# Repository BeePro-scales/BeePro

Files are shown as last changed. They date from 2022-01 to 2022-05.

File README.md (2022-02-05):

# BeePro Sms Scales
#### Hardware Design Files [Here](/Hardware)
#### Firmware file [Here](/firmware)
#### Assembly Instructions [Here](/AssemblyInstructions.md)
#### How to set the scales [Here](/Settings.md)

#### Technical Characteristics
Humidity measurement: 0 to 100% RH operating range, precision :± 4% RH (max), 0–80% RH
Temperature measurement: -25 to +60 C, ±0.4 °C (max), –10 to 85 °C
Power source: 18650 Li-Ion battery
Standby power consumption: ~1 µA (microampere)

#### SMS Of Daily Report
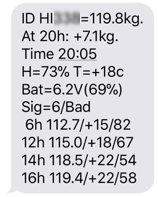
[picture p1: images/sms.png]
Sms
     
Lines
1. Scales ID and hive weight at 8pm
2. Daily beehive weight change
3. Scales time
4. Current humidity and temperature
5. Battery volts and remaining charge
6. GSM network signal quality range from 1 to 33
7. 6 hour hive weight, temperature and humidity
8. 12 hour hive weight, temperature and humidity
9. 14 hour hive weight, temperature and humidity
10. 16 hour hive weight, temperature and humidity

#### Over 1 Kg Change In 1 Hour Report
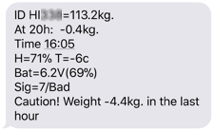
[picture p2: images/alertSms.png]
Sms Alert
   
Lines
1. Scales ID and hive weight at 8pm
2. Daily beehive weight change
3. Scales time
4. Current humidity and temperature
5. Battery volts and remaining charge
6. GSM network signal quality range from 1 to 33
7. Weight change in last hour

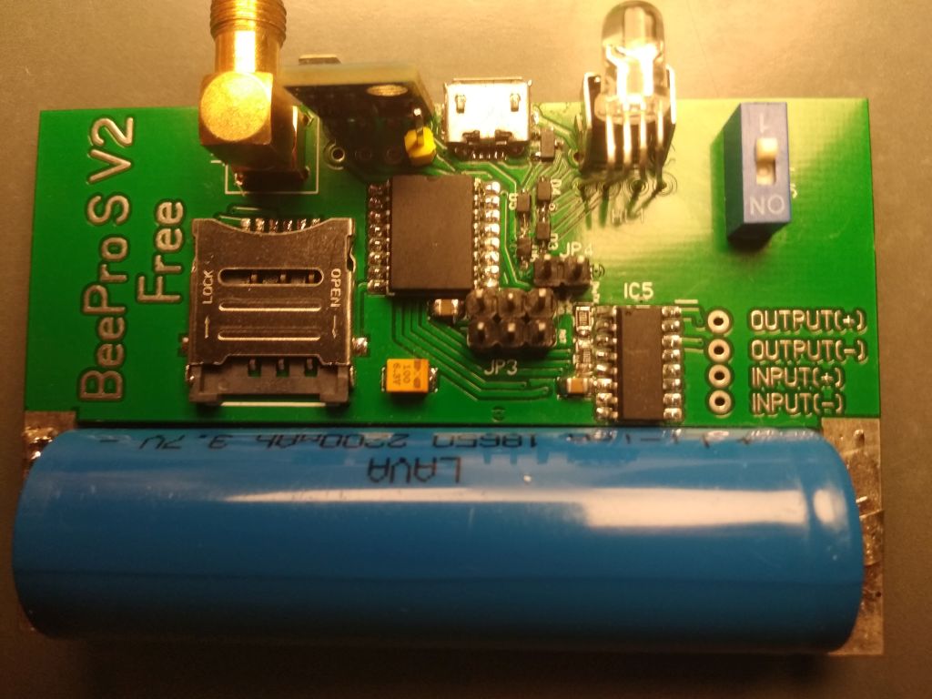
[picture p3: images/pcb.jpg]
SmsScales


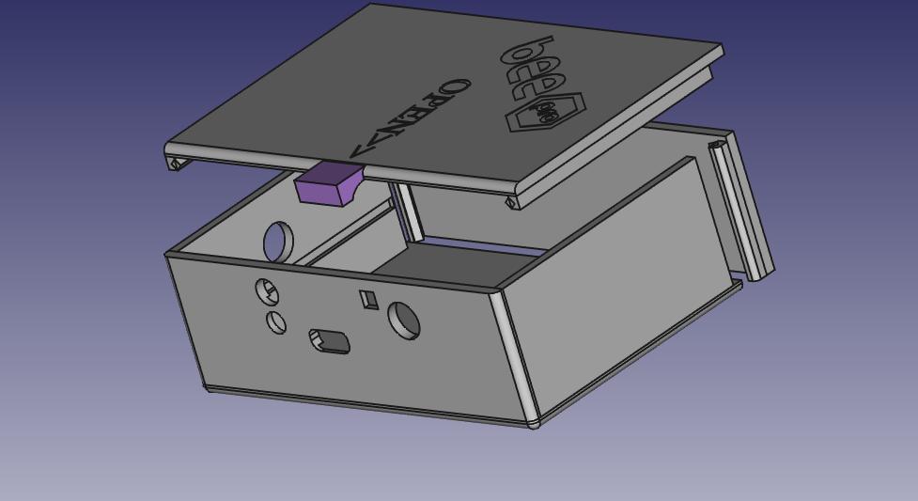
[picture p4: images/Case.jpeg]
3d Model


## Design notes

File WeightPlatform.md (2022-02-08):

# We make

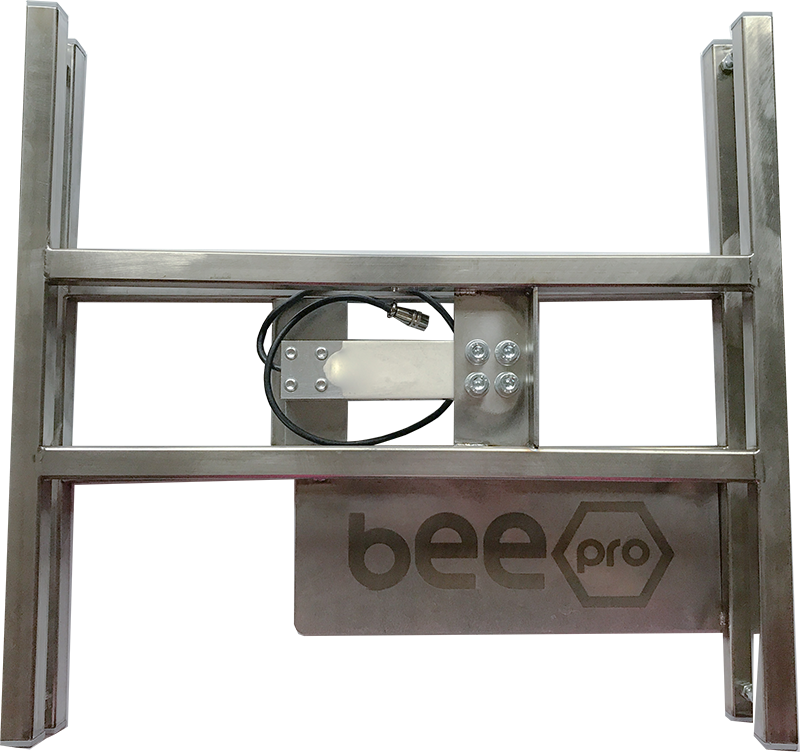
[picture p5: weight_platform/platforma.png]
Platform with sensor


# Under the hive 

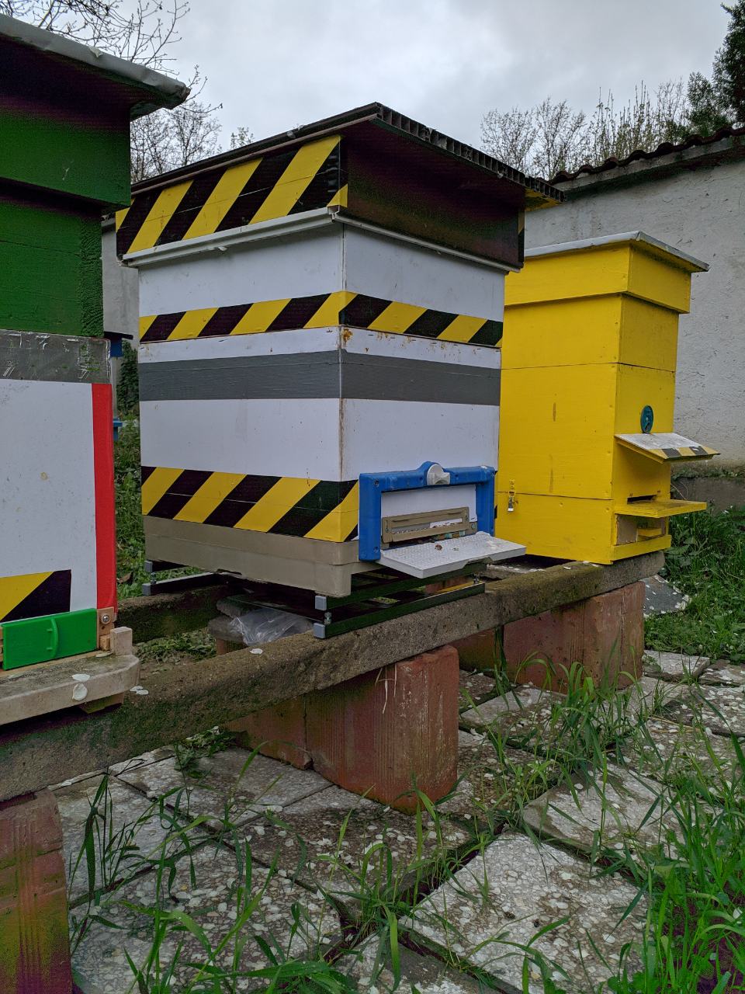
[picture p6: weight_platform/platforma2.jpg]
Platform under the hive


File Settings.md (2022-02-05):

#### Functions for scales without a screen:

Short click <3 seconds. If LED blinks for 2 times - the scales are alive and working.

Information that scales provide:

F0.1 +30000000000 LA256 4.00 01/01/2000 00:17:13
hg: 34 cls: 23 wg: 0.00

Explanation:

  - F0.1 - software version;
  - +30000000000 - phone number scales send SMS to;
  - LA256 - Unique scales ID;
  - 4.00 - battery volts;
  - 01/01/2000 00:17:13 - Scales date and time;
  - hg: 34 - Humidity;
  - cls: 23 - Temperature;
  - wg: 0.00 - Day weight difference;

#### Test and calibration mode:

-- Calibration mode:

  Hold the power button till LED turns blue, then release click:
    - Calibration mode is on for 15 seconds. You’ll need to add 1kg. weight on the scales in this period (15 seconds ).
    - In case calibration was successful - the LED blinks 2 times in green color and this means that calibration is done.

    If LED blinks 3 times in red color - calibration failed, this could be for many reasons (unconnected platform, bad sensor, etc.)

#### Send a test SMS message:

  Hold the power button till LED turns blue, hold for another 3 seconds ( do not release click when LED turns blue), when LED turns green, release click :
  
  This will send a test SMS message.

    If LED blinks 2 times in red - scales does not have master phone number (you need to set it in the scales settings )

#### Functions for scales with a screen:

Click and hold the power button for 3 seconds, when LED turns red - release click :

Screen menu :

1. Test Hardware
2. Send a Test SMS
3. Change/Add Master Number
4. Set ID
5. Set Date/Time
6. Power Off

Explanation of menu items:

1. Test Hardware - test SI7020 sensor:
  - If the test is successful, see this on the screen:

    Test RTC: OK Date: 01/01/2000 00:00:52
    Test SI7020: OK H%: 32 Celsius: 20

  - If the test failed, see this on the screen:

    Test RTC: FAIL
    or
    Test SI7020: FAIL

2. Send a Test SMS - Send a test SMS and test the GSM module.
3. Change/Add Master Number - Set the main (master) phone number to where to send the day report (scales send a report every day at 20:00 ).
4. Set ID - Set unique scales ID (this ID is visible in the SMS message )
5. Set Date/Time - Set scales date and time.
6. Power Off - Turn off scales.

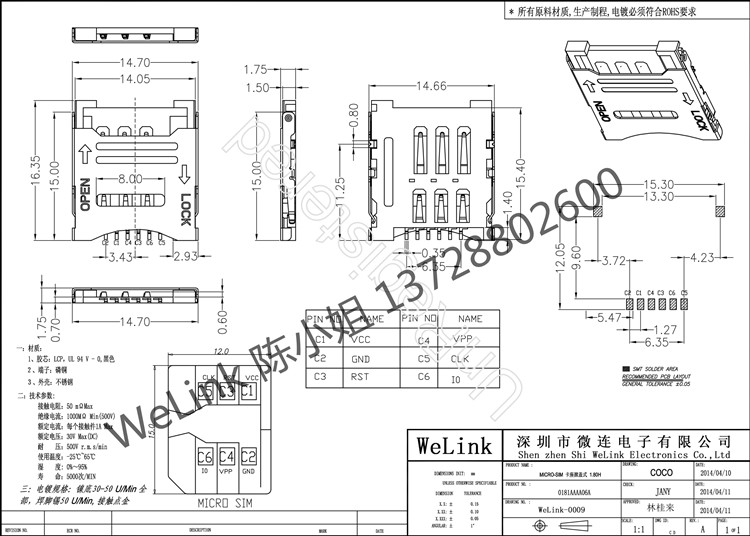
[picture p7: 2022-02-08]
Hardware/SimHolder.jpg

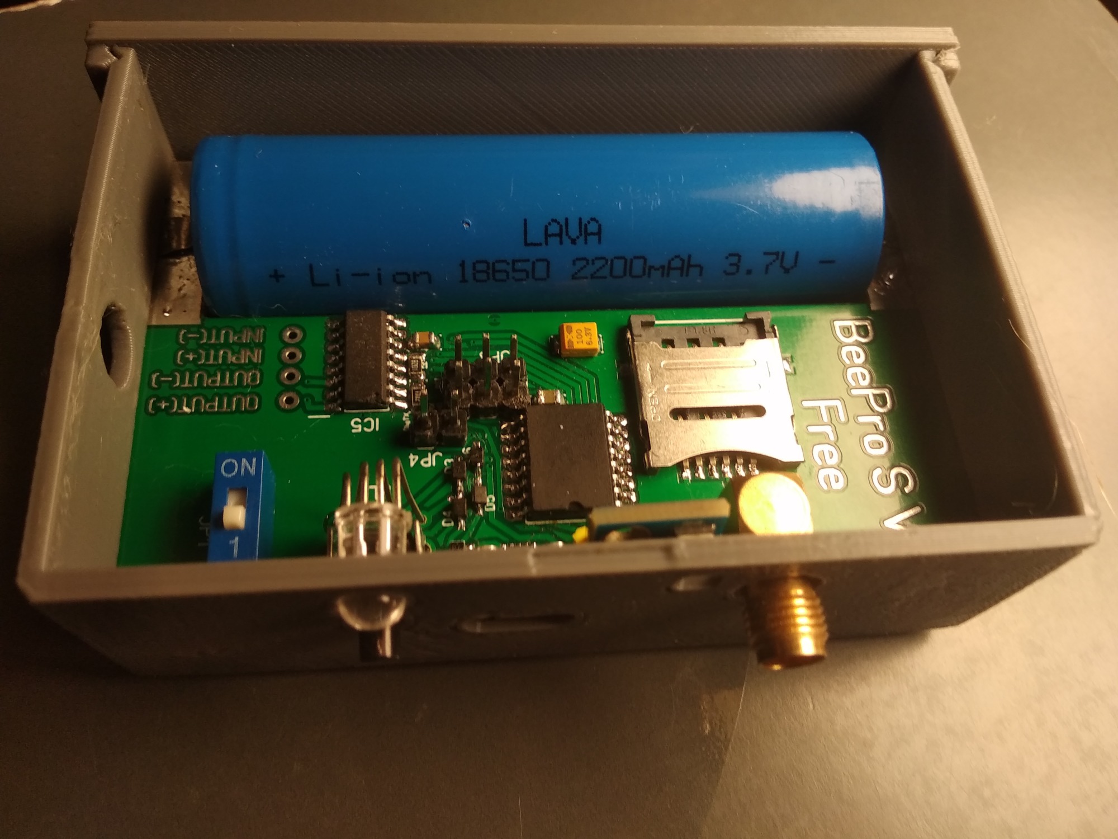
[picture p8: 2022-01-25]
images/pcbWithCase.jpg

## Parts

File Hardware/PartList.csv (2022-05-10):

No | Name | Value | Layer | Package
1 | C1 | 100uf | Top | 805
2 | C2 | 0,1uf | Top | 603
3 | C3 | 1Uf | Top | 805
4 | C4 | 1Uf | Bottom | 805
5 | C5 | 1Uf | Top | 805
6 | C6 | 0,1uf | Top | 805
7 | C6 | 1Uf | Top | 805
8 | C7 | 0,1uf | Top | 805
9 | C8 | 100uf | Bottom | 805
10 | C9 | 47Uf | Bottom | 805
11 | C10 | 47Uf | Top | 805
12 | C11 | 10uf | Top | 805
13 | IC2 | DS3231SN | Bottom | 805
14 | IC3 | Atmega328 | Top | TQFP32 Fuse : Low 0xE2 High 0xD7 Extended 0xFE
15 | IC4 | TP4057 | Top | SOT-23-6
16 | IC5 | HX711 | Bottom | SOP-16L
17 | P1 | G27Y | Bottom | ---
18 | Q1 | SI2329DS | Top | SOT-23
19 | Q2 | SI2329DS | Top | SOT-23
20 | Q3 | MMBT2222A | Top | SOT-23
21 | Q4 | MMBT2222A | Top | SOT-23
22 | Q5 | MCP1702-3.0 | Top | SOT-23A
23 | Q6 | DTA113ZCA | Top | SOT-23
24 | Q7 | DTA113ZCA | Bottom | SOT-23
Q8 MMBT2222A Bottom | SOT-23
25 | R1 | 47k | Top | 805
26 | R2 | 150R | Top | 805
27 | R3 | 47k | Top | 805
28 | R4 | 510R | Top | 805
29 | R6 | 47k | Top | 805
30 | R7 | 510R | Top | 805
31 | R7 | 510R | Top | 805
32 | R8 | 510R | Top | 805
33 | R9 | 47k | Top | 805
34 | R10 | 330R | Top | 805
35 | R11 | 150R | Top | 805
36 | R12 | 8.2K | Bottom | 805
37 | R13 | 10K | Bottom | 805
38 | R14 | 10K | Top | 805
39 | R15 | 1,6K | Top | 805
R16 510R Bottom | 805
40 | U2 | A9 | Top | 805
41 | ANT | 14.5mm | Top | SMA Female Thru Hole plug Right Angle 90 DEGREE ( SMA-KWE ) PCB Mount Connector RF
42 | BAT | Li-Ion | Top or Bottom | 18650 Battery with solder tabs (Rechargeable)
43 | SIM | Sim holder | Bottom | WeLink-0009

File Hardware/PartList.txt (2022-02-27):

* Partlist : 2022-02-08 16:15:27

See partlist here - https://github.com/BeePro-scales/BeePro/blob/main/Hardware/PartList.csv

Simholder example: https://github.com/BeePro-scales/BeePro/blob/main/Hardware/SimHolder.jpg

Feel free to ping us at beeproscales@gmail.com - if you're intrested to buy parts "KIT"

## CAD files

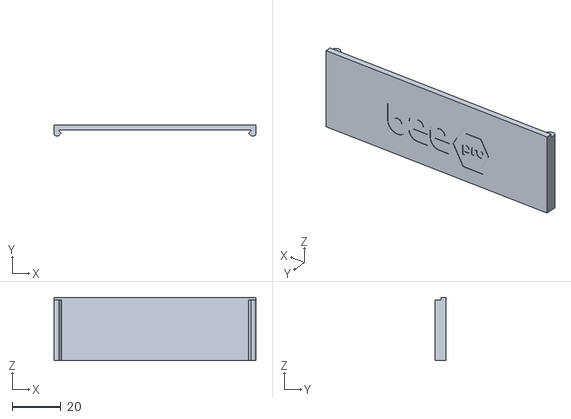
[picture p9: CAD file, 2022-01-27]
Case/tail.stl
83.0 x 4.50 x 26.0

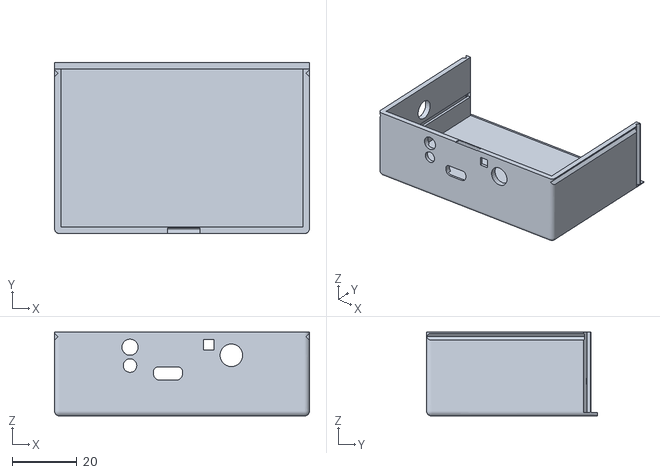
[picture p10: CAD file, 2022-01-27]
Case/case.stl
79.0 x 53.0 x 26.0

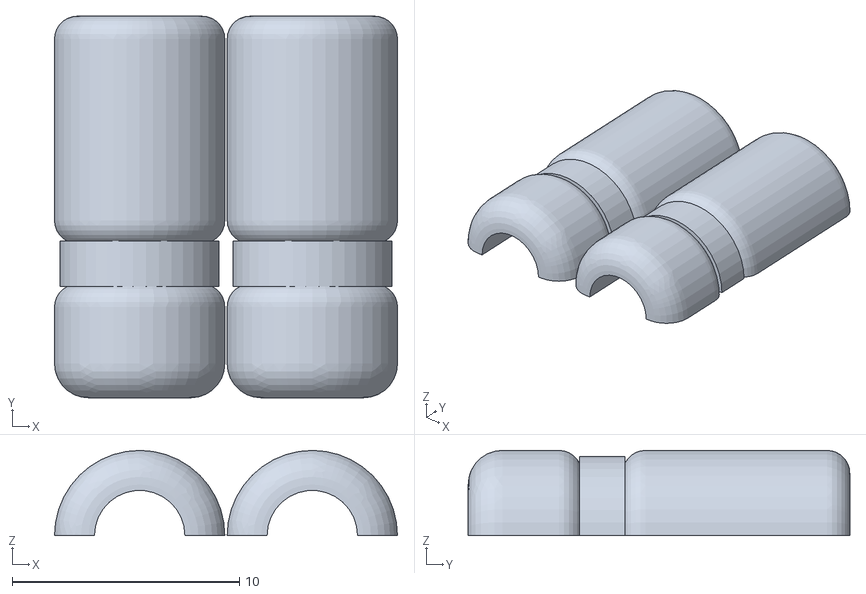
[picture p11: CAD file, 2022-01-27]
Case/cable_holder .stl
15.1 x 16.8 x 3.75

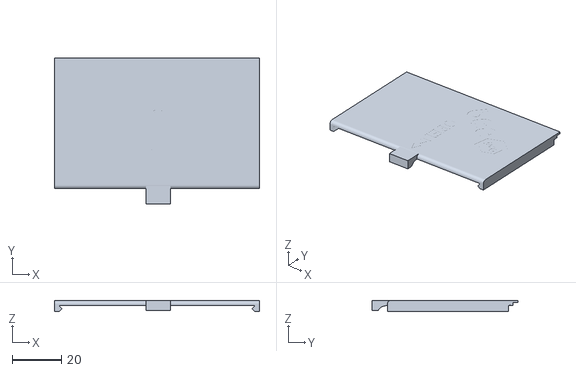
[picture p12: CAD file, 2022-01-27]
Case/cover.stl
83.0 x 59.2 x 4.50

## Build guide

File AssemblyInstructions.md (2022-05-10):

Solder parts from this list : [PartList](/Hardware/PartList.csv)

Following these 2 images (* improved images) :

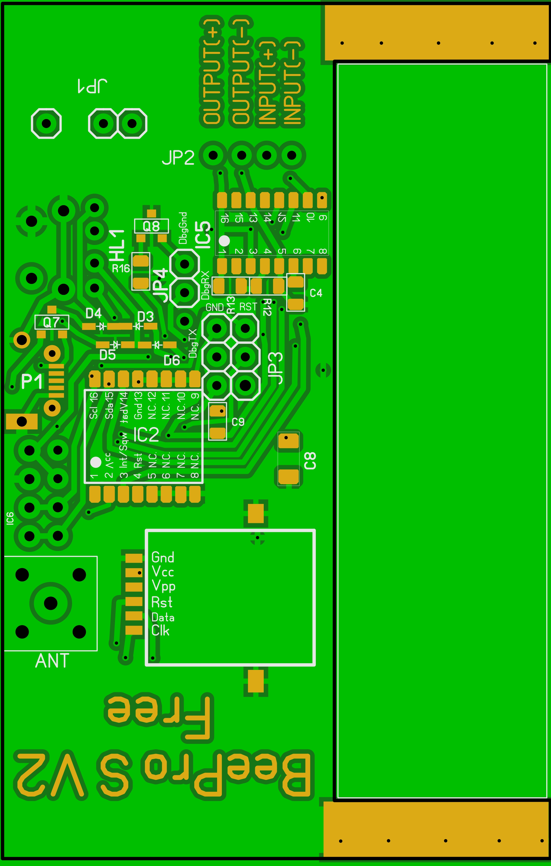
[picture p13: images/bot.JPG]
Bottom part 

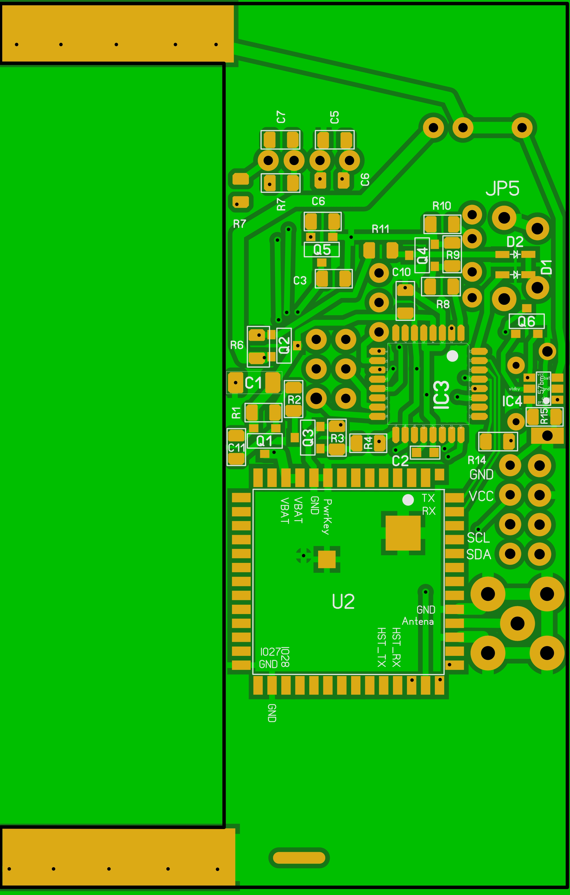
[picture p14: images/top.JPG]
Top part 

## After soldering, the PCB must be thoroughly washed from the solder pasta (flux)

# Some important things to know:

#### SI7021 module preparation.

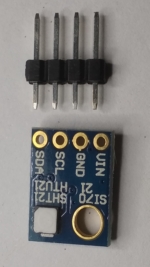
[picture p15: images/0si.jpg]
0si
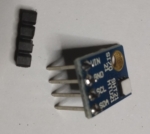
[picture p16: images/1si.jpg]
1si
Solder module -  remove plastic -  fold the contacts - 2si

#### Instructions for a battery solder.

Place corpus on a flat surface ( side is not important ), then solder battery into it.

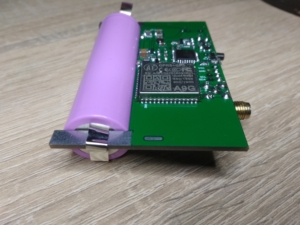
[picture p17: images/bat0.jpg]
bat0
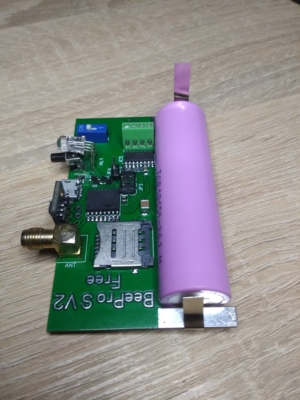
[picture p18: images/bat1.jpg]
bat1
 arba 

#### Last but not least - Cover open contacts with a PCB varnish.

# Old platform images ( just for a reference )

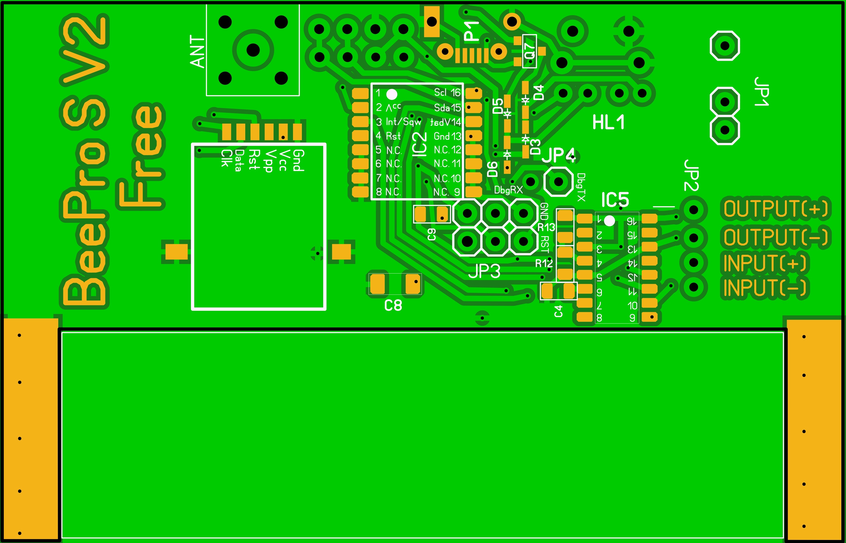
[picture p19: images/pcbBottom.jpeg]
Bottom Side
Bottom part 

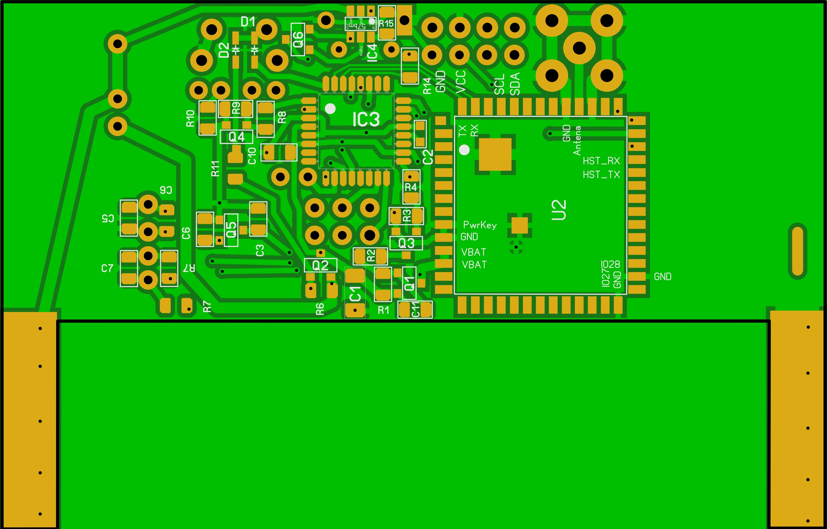
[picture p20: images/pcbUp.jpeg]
Top part

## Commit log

2022-01-27 3D models of the case
    [cable_holder .stl, case.stl, cover.stl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]
2022-02-27 .csv part list
    [PartList.csv]
2022-02-27 Table fix
    [PartList.csv]
